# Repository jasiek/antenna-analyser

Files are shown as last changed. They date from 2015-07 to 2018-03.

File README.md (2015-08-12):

# antenna-analyser

There's a few projects like this one out there on the net. My goal was to create one that would be properly productized - eg.
with a PCB ready to be made and a parts list that can be easily obtained on eBay, etc.

The circuit is [K6BEZ's design](https://sites.google.com/site/k6bezprojects/antenna-analyser), and uses
an [Arduino Pro Mini](https://www.arduino.cc/en/Main/ArduinoBoardProMini), running at 8Mhz and 3.3V with
a cheap [SPI LCD TFT display](http://www.electrodragon.com/product/eds-tft-lcd-lcm-spi-interface-variable1-82-2)
to graphically represent the results of VSWR analysis.

I've bundled everything together into one repository so that the project can quickly be opened up in [KiCad](http://www.kicad-pcb.org/)
and the Arduino IDE.

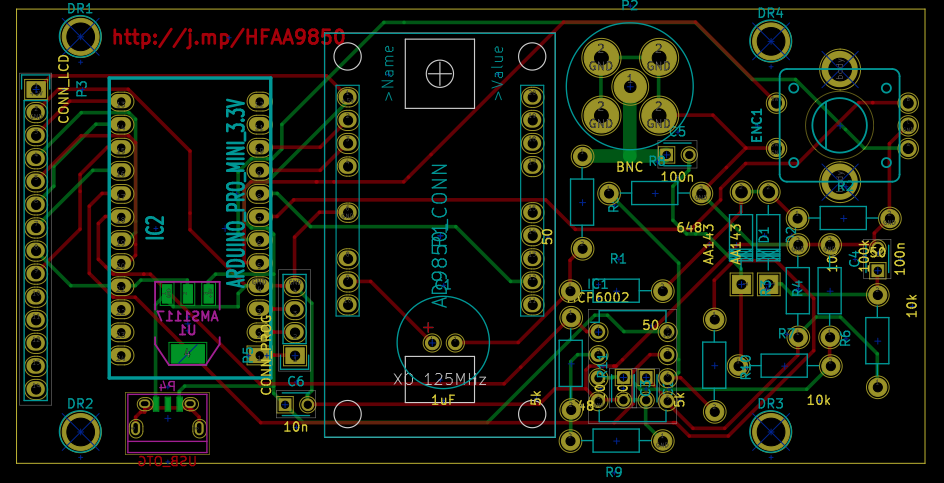
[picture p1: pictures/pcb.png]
PCB

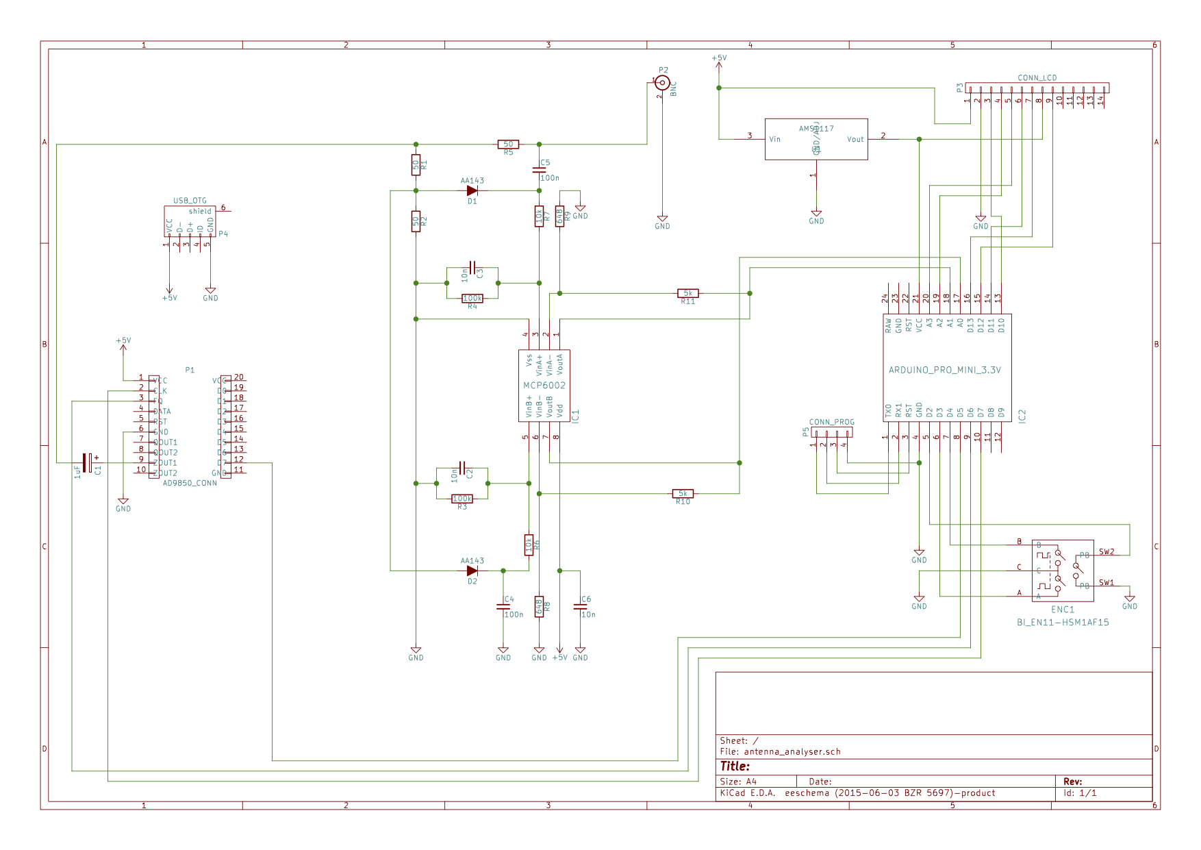
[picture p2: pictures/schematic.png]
Schematic


## A few photos of the first prototype

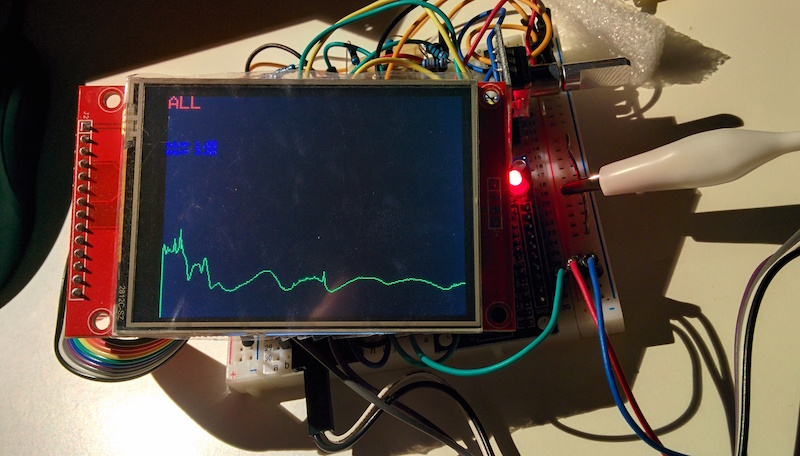
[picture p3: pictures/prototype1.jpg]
Prototype

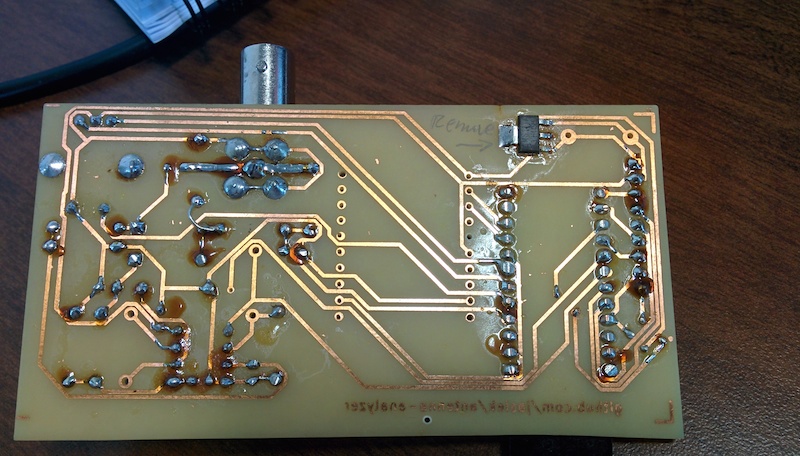
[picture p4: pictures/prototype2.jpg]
Back of PCB

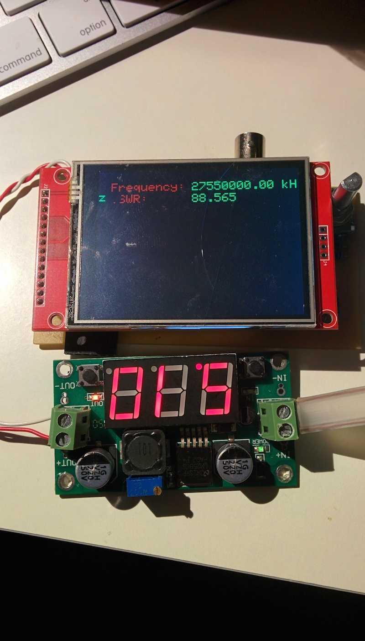
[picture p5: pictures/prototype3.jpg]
Assembled Prototype


## A few shots of the UI

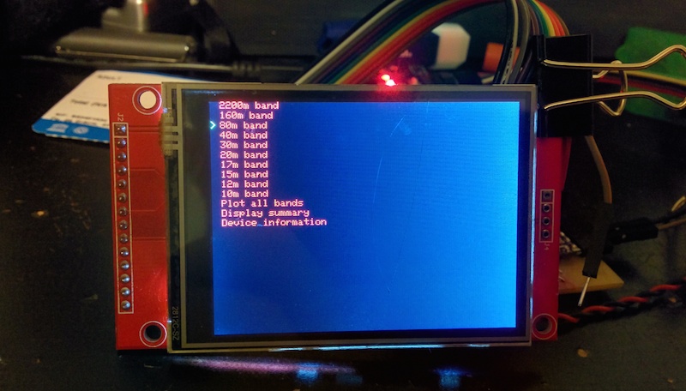
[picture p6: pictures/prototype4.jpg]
Main menu

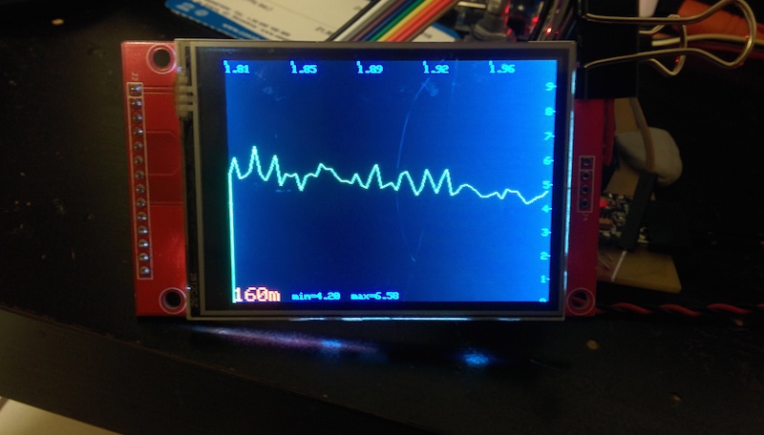
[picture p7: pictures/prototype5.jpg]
Single band plot

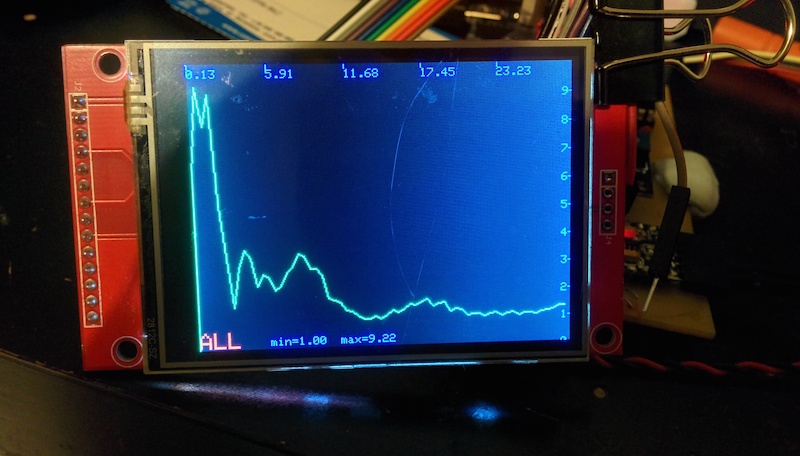
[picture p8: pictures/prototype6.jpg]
All bands plot

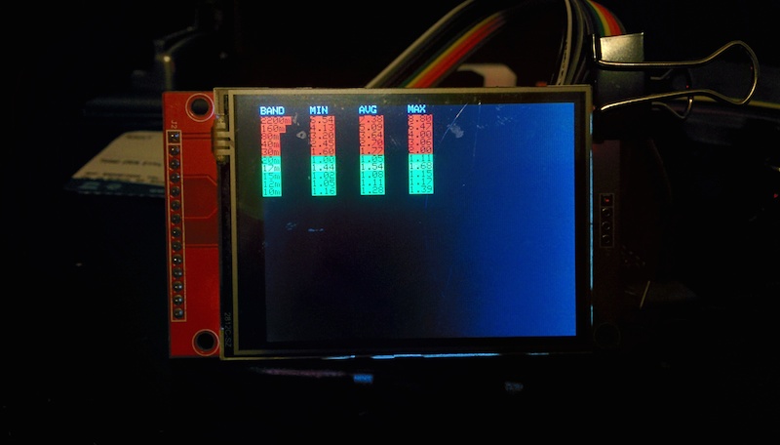
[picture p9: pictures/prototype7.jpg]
Summary table


## TODO

* Build and test this branch as a functional, physical prototype.
* ~~Improve menu structure and navigation.~~
* ~~Improve single band plot (move band label, min, max to the bottom). Notify the user when done plotting.~~
* When plotting all bands, plot amateur bands using a different colour.
* ~~Improve summary view, label columns, shorten frequency label.~~
* Add menu which lists 20 SWR minima across the band.

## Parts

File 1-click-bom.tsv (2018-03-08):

References | Qty | Description | Manufacturer | MPN | Digikey | Mouser | RS | Newark | Farnell
C1 | 1 | 1uF THT | Panasonic | ECA-2GM010
C3, C6, C2 | 3 | 10nF THT | Murata | DSN6NZ81H103Q55B
C5, C4 | 2 | 100nF THT | AVX | TAP104K035SCS
D1, D2 | 2 | AA143 Diode | Microsemi | AA143
ENC1 | 1 | BI EN11-HSM1AF15 | BI Technologies | EN11-HSM1AF15
IC1 | 1 | MCP6002 | Microchip | MCP6002-I/P
IC2 | 1 | Arduino Pro Mini | SparkFun | 11114
P1 | 1 | AD9850 CONN DDS
P2 | 1 | BNC Connector |  | 5-1634556-0
P3 | 1 | CONN 01X14 LCD Connector, single row, 01x14, pin header Socket Strip Straight 1x14 |  | 9-146281-0
P4 | 1 | USB Micro-B | TE Connectivity | 1981568-1
P5 | 1 | CONN 01X04 PROG Connector, single row, 01x04, pin header Socket Strip Straight 1x04 |  | 9-146281-0
R2, R1, R5 | 3 | 50 Ohm THT Resistor |  | PTF5650R000BYEK
R4, R3 | 2 | 100k THT Resistor |  | MF12 100K
R7, R6 | 2 | 10k THT Resistor |  | MF12 10K
R9, R8 | 2 | 648 Ohm THT Resistor |  | RN60C6490FB14
R10, R11 | 2 | 5k THT Resistor |  | RN55C5001BRE6
U1 | 1 | AMS1117-3.3 | Advanced Monolithic Systems | AMS1117-3.3

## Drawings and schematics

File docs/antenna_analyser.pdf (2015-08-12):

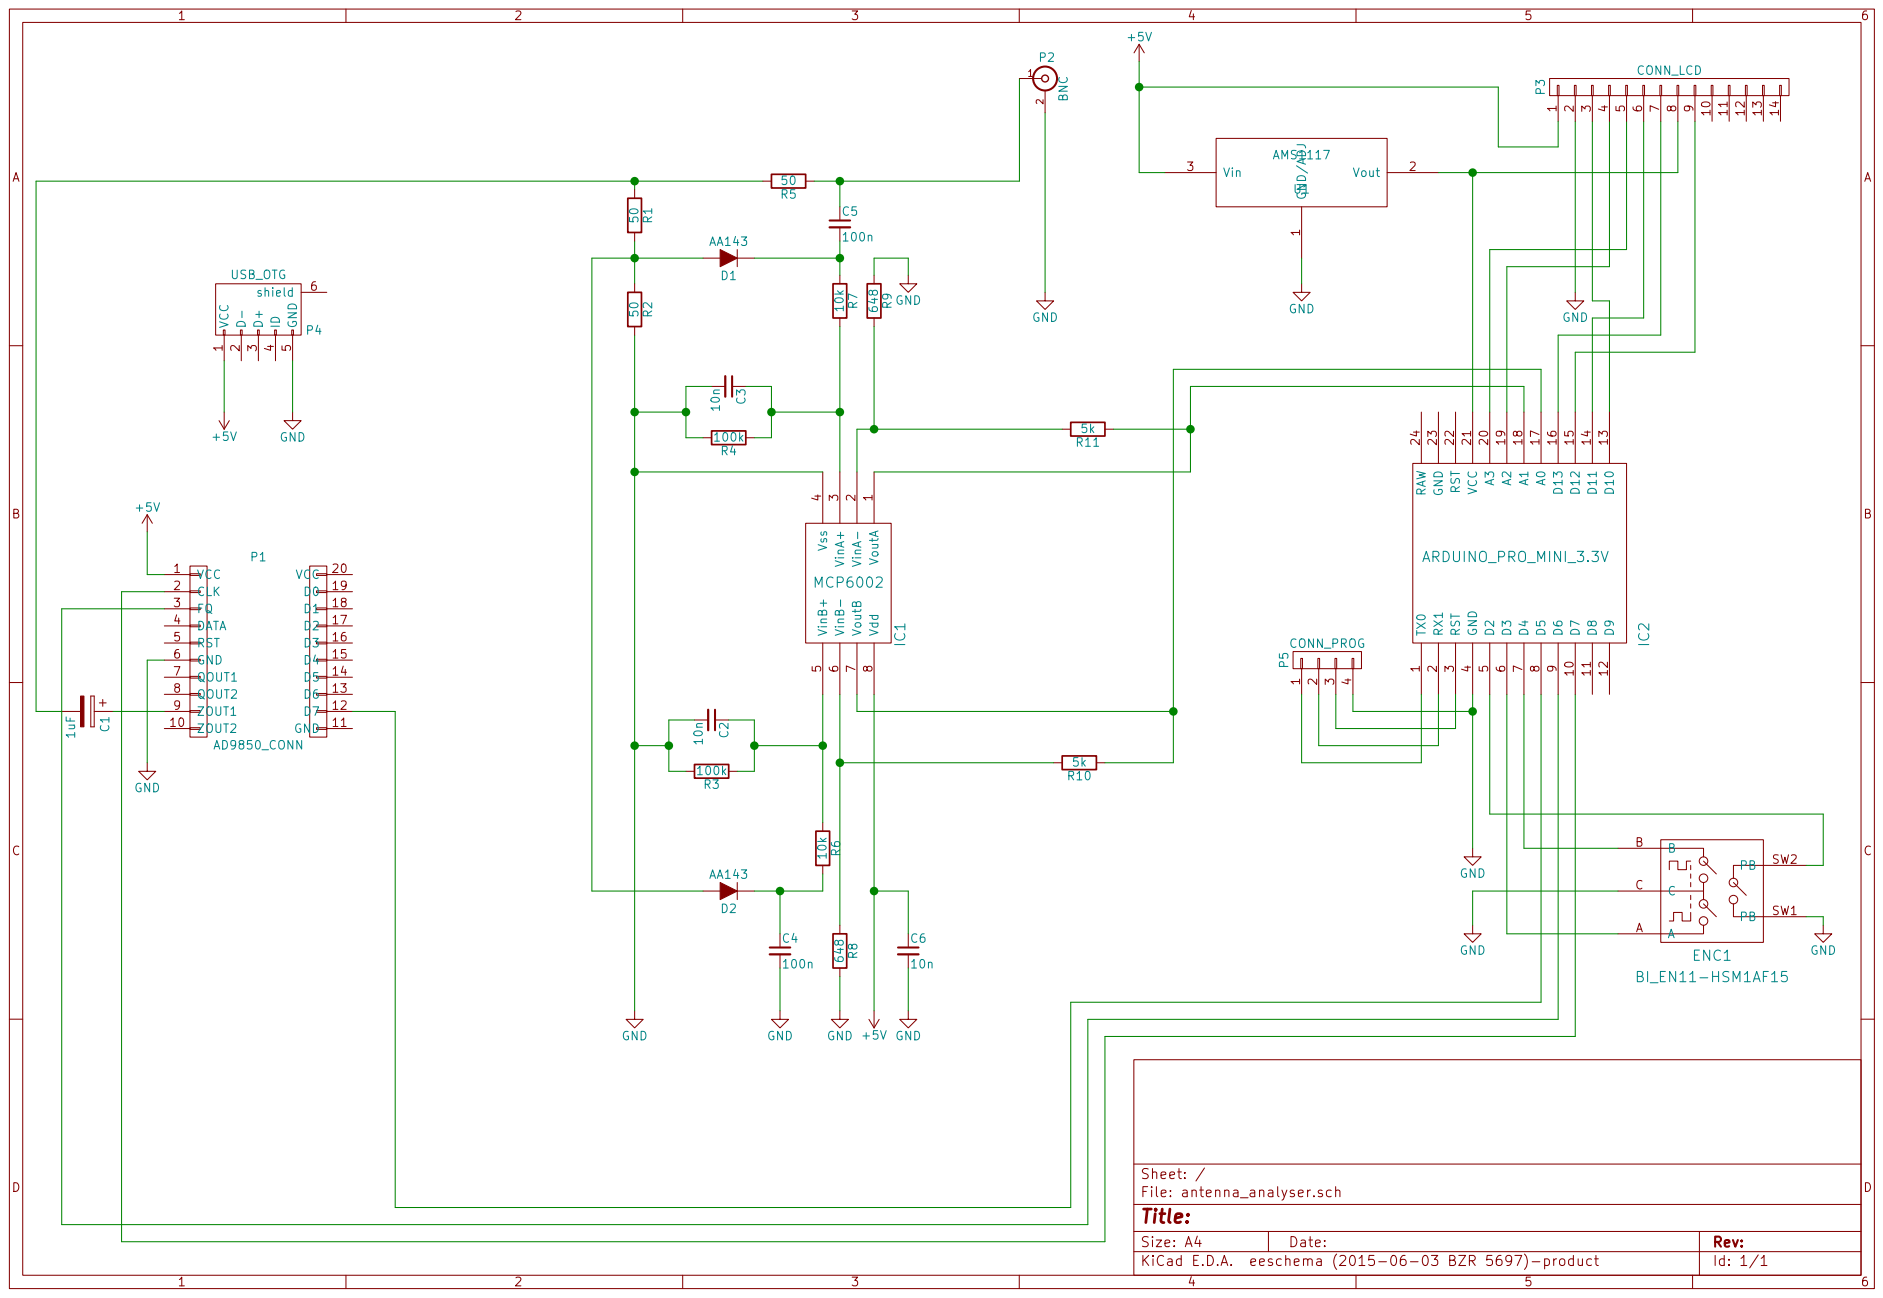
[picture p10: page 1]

2 P2 BNC GND GND VCC

9 D7 10 A3 20 D8 11 VCC 21 D9 12 RST 22 D10 13 GND 23 D11 14 RAW 24 D12 15 D13 16 A0 17 A1 18 A2 19 IC2

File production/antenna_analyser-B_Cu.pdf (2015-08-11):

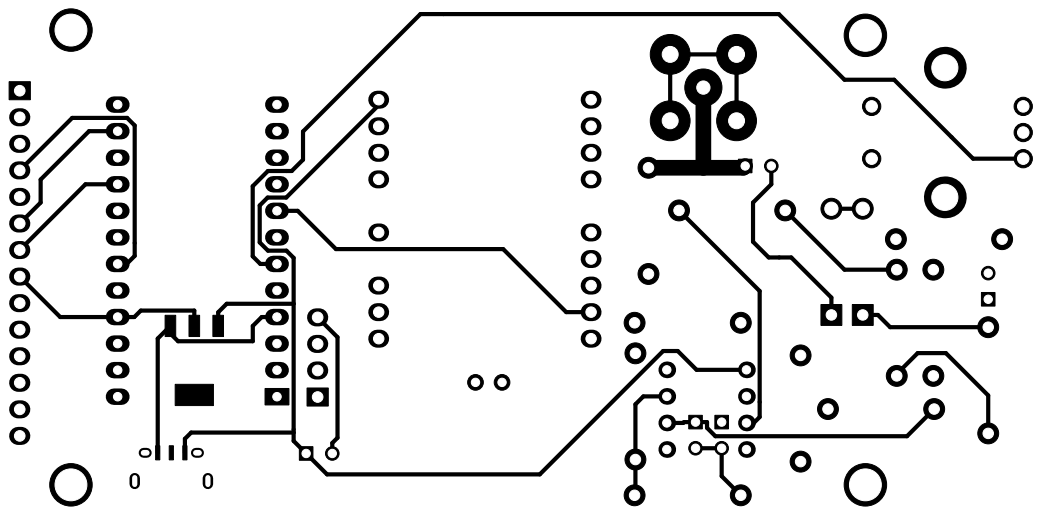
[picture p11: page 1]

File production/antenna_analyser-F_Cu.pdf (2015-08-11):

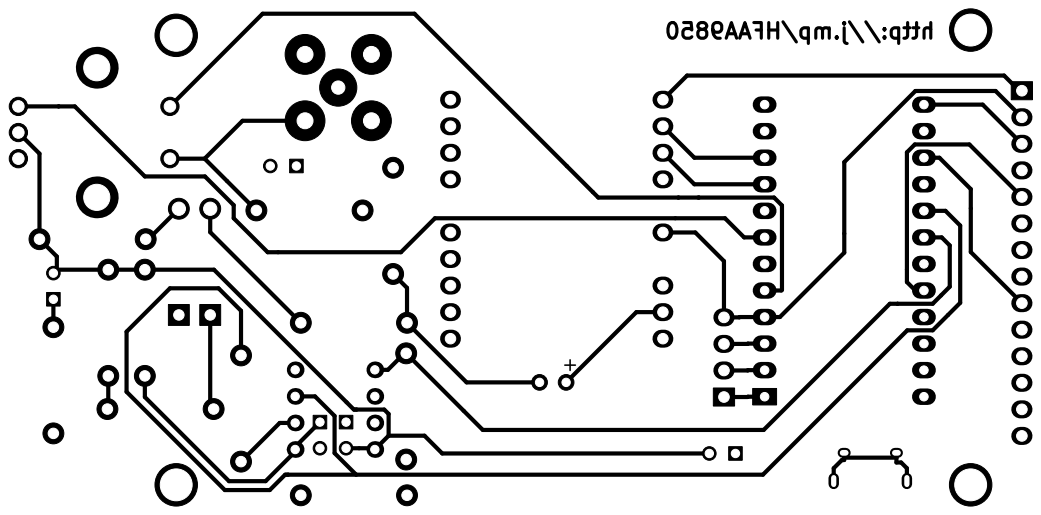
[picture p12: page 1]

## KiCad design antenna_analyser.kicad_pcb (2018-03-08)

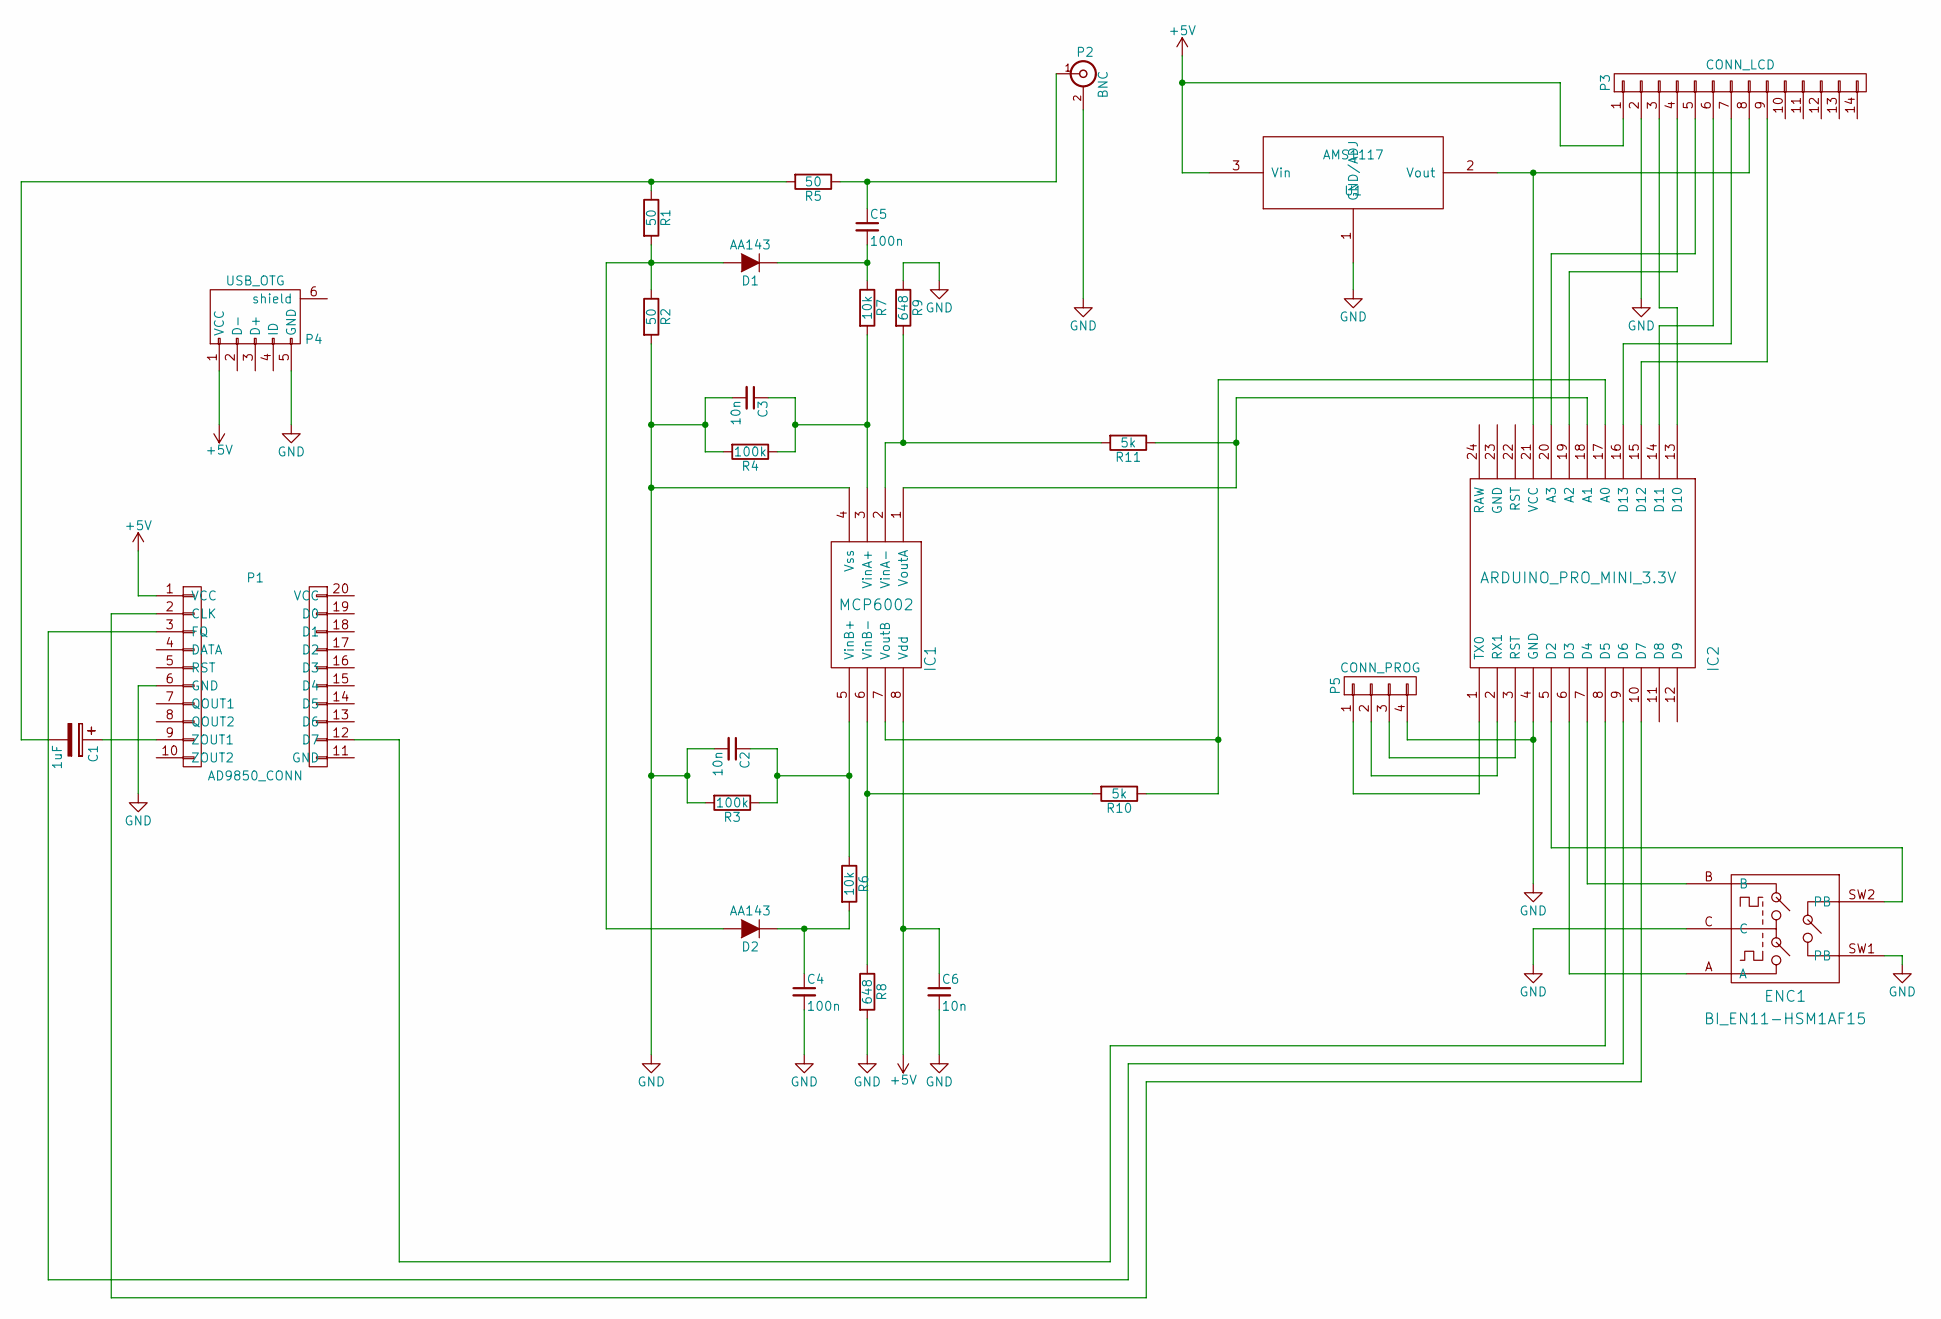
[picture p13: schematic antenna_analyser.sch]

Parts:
C1: 1uF; Elko_vert_20x10mm_RM2.5
C2, C3, C6: 10n; C_Disc_D3_P2.5
C4, C5: 100n; C_Disc_D3_P2.5
D1, D2: AA143; Diode_DO-41_SOD81_Horizontal_RM10
ENC1: BI_EN11-HSM1AF15; BI_EN12-HS22AF30
IC1: MCP6002; DIP-8_W7.62mm
IC2: ARDUINO_PRO_MINI_3.3V; ARDUINO_PRO_MINI
P1: AD9850_CONN; DDS_AD9850
P2: BNC; bnc-ci
P3: CONN_LCD; Socket_Strip_Straight_1x14
P4: USB_OTG; USB_Micro-B
P5: CONN_PROG; Socket_Strip_Straight_1x04
R1, R2, R5: 50; Resistor_Horizontal_RM10mm
R3, R4: 100k; Resistor_Horizontal_RM10mm
R6, R7: 10k; Resistor_Horizontal_RM10mm
R8, R9: 648; Resistor_Horizontal_RM10mm
R10, R11: 5k; Resistor_Horizontal_RM10mm
U1: AMS1117; SOT223

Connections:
+5V: C6.1, IC1.8 (Vdd), P1.1 (VCC), P3.1, P4.1 (VCC), U1.3 (Vin)
GND: C2.2, C3.2, C4.2, C6.2, ENC1.C, ENC1.SW1 (PB), IC1.4 (Vss), IC2.4 (GND), P1.6 (GND), P2.2 (Ext), P3.2, P4.5 (GND), P5.4, R2.2, R3.2, R4.2, R8.2, R9.1, U1.1 (GND/ADJ)
unnamed: C1.1, P1.9 (ZOUT1)
unnamed: C1.2, R1.1, R5.2
unnamed: C2.1, IC1.5 (VinB+), R3.1, R6.1
unnamed: C3.1, IC1.3 (VinA+), R4.1, R7.2
unnamed: C4.1, D2.1 (K), R6.2
unnamed: C5.1, P2.1 (In), R5.1
unnamed: C5.2, D1.1 (K), R7.1
unnamed: D1.2 (A), D2.2 (A), R1.2, R2.1
unnamed: ENC1.A, IC2.6 (D3)
unnamed: ENC1.B, IC2.7 (D4)
unnamed: ENC1.SW2 (PB), IC2.5 (D2)
unnamed: IC1.1 (VoutA), IC2.18 (A1), R11.1
unnamed: IC1.2 (VinA-), R9.2, R11.2
unnamed: IC1.6 (VinB-), R8.1, R10.2
unnamed: IC1.7 (VoutB), IC2.17 (A0), R10.1
unnamed: IC2.1 (TX0), P5.1
unnamed: IC2.2 (RX1), P5.2
unnamed: IC2.3 (RST), P5.3
unnamed: IC2.8 (D5), P1.12 (D7)
unnamed: IC2.9 (D6), P1.3 (FQ)
unnamed: IC2.10 (D7), P1.2 (CLK)
unnamed: IC2.13 (D10), P3.3
unnamed: IC2.14 (D11), P3.6
unnamed: IC2.15 (D12), P3.9
unnamed: IC2.16 (D13), P3.7
unnamed: IC2.19 (A2), P3.4
unnamed: IC2.20 (A3), P3.5
unnamed: IC2.21 (VCC), P3.8, U1.2 (Vout)

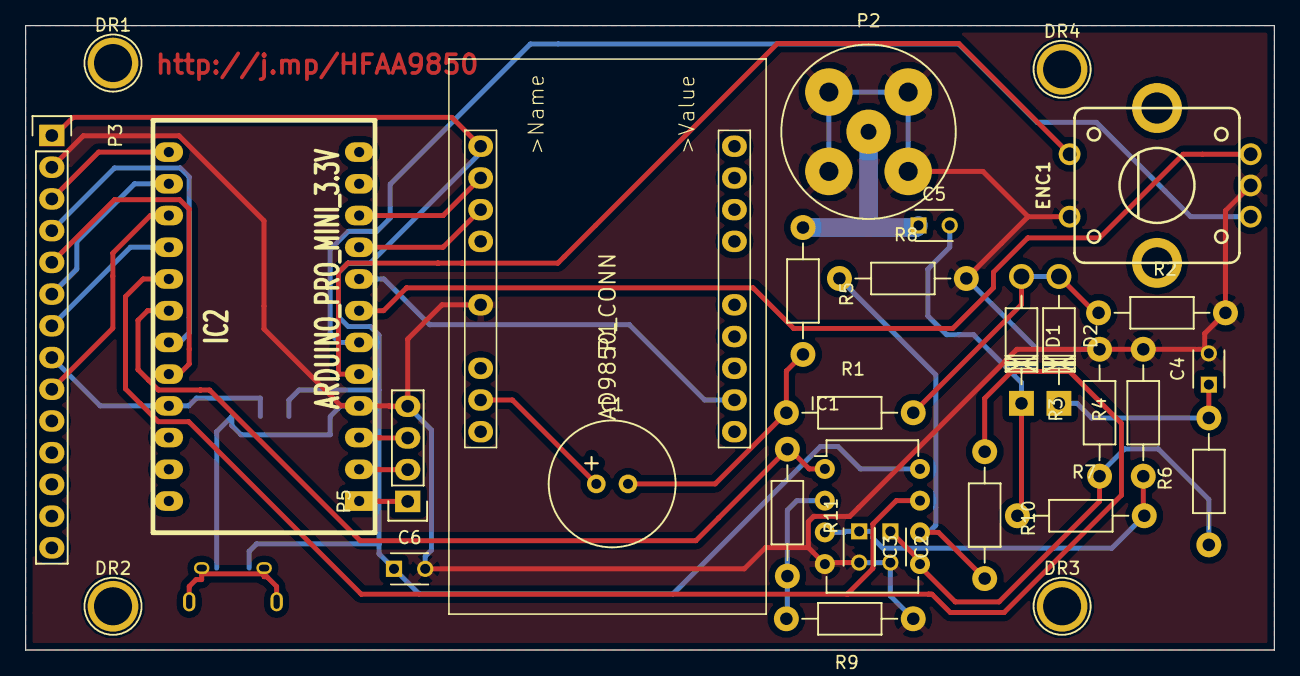
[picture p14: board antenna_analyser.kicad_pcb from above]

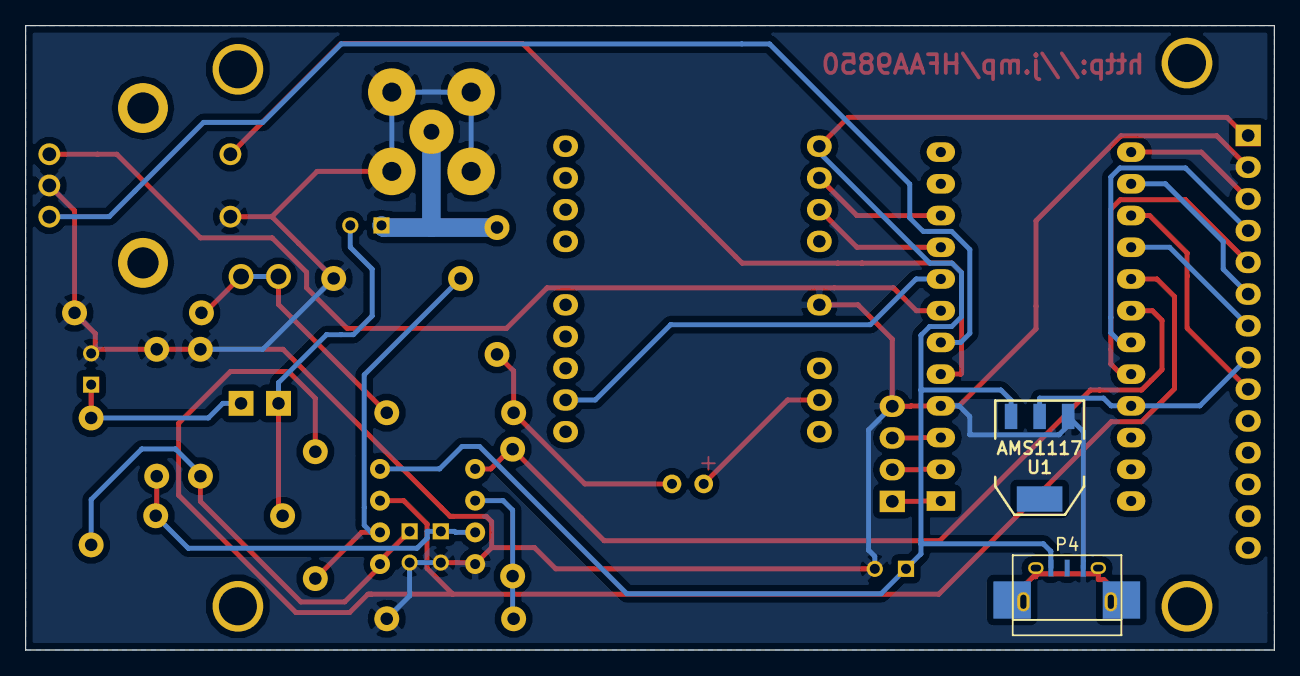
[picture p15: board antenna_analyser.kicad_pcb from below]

Board: 2 copper layers, 100.0 x 50.0 mm, 32 parts (2 on the bottom side), 30 nets.

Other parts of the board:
DR1, DR2, DR3, DR4: 1pin

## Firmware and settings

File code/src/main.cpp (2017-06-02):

#include "SPI.h"
#include "Adafruit_GFX.h"
#include "Adafruit_ILI9341.h"
#include <AD9850.h>

#define BACKGROUND ILI9341_BLACK
#define X_TICS 5
#define Y_TICS 10

#define TABLEN 50
#define T0 0
#define T1 T0 + TABLEN
#define T2 T1 + TABLEN
#define T3 T2 + TABLEN
#define T4 T3 + TABLEN

// Analog pins are used for communication to make the circuit fit on a PCB easier.
Adafruit_ILI9341 tft = Adafruit_ILI9341(10, A3, A2);
AD9850 ad9850;

const String nameOfBand[] =  { "2200m",    "160m",     "80m",    "40m",    "30m",    "20m",    "17m",    "15m",      "12m",    "10m"   };
const double startOfBand[] = { 135.7E3,    1.81E6,     3.5E6,    7E6,      10.1E6,   14E6,     18.068E6,  21E6,      24.89E6,  28E6    };
const double endOfBand[] =   { 137.8E3,    2E6,        3.8E6,    7.2E6,    10.15E6,  14.35E6,  18.168E6,  21.450E6,  24.99E6,  29.7E6  };
const double steps[] =       { 100,        3E3,        3E3,      3E3,      300,      3E3,      3E3,       3E3,       3E3,      6E3     };
const int numBands = 10;

// What kind of actions can be performed using the rotary encoder?
typedef enum {
  NONE,
  CLICK,
  LEFT,
  RIGHT
} Action;

float measureSWR(double f);
void drawXAxis(double begin, double end, byte nticks);
void drawYAxis(byte nticks);
void drawXAxisLabels(String bandLabel);
void sweepBand(double begin, double end, double step, float *min, float *avg, float *max);
void displayPlot(double begin, double end, String label);
void rollHandler();
void clickHandler();
byte awaitAction();
void displaySingleBand(byte band);
void displayAllBands();
void displaySummary();
void displayInfo();
byte mainMenu();

void setup() {
  pinMode(2, INPUT_PULLUP); // Rotary encoder CLK
  pinMode(3, INPUT_PULLUP); // Rotary encoder CLICK
  pinMode(4, INPUT_PULLUP); // Rotary encoder DATA

  Serial.begin(57600);
  tft.begin();
  Serial.println("Width: " + String(tft.width()) + " Height: " + String(tft.height()));
  tft.setRotation(3);
  ad9850.begin(7, 6, 5, 0);
}

void loop() {
  byte nextUIState = 100;

  while(1) {
    tft.fillScreen(BACKGROUND);

    switch(nextUIState) {
      case 100:
        nextUIState = mainMenu();
        break;
      case numBands:
        displayAllBands();
        nextUIState = 100;
        break;
      case numBands + 1:
        displaySummary();
        nextUIState = 100;
        break;
      case numBands + 2:
        displayInfo();
        nextUIState = 100;
        break;
      default:
        displaySingleBand(nextUIState);
        nextUIState = 100;
        break;
    }
  }
}

// Display the main menu and handle view changes resulting from the operation of the
// rotary encoder.
// Returns to calling function when this menu is dismissed, communicating the menu state up the chain.
byte mainMenu() {
  const byte menuEntries = numBands + 3;
  byte menuState = 0;
  byte i;
  tft.setTextSize(1);
  tft.setTextColor(ILI9341_RED, BACKGROUND);
  for (i = 0; i < numBands; i++) {
    tft.setCursor(10, i * 10);
    tft.print(nameOfBand[i] + " band");
  }

  tft.setCursor(10, 10 * (numBands));
  tft.print("Plot all bands");
  tft.setCursor(10, 10 * (numBands + 1));
  tft.print("Display summary");
  tft.setCursor(10, 10 * (numBands + 2));
  tft.print("Device information");

  while (1) {
    for (i = 0; i < menuEntries; i++) {
      tft.setCursor(0, i * 10);
      if (menuState == i) { tft.setTextColor(ILI9341_YELLOW, BACKGROUND); } else { tft.setTextColor(BACKGROUND, BACKGROUND); }
      tft.print(">");
    }

    switch(awaitAction()) {
      case CLICK:
        return menuState;
      case LEFT:
        menuState = (menuState - 1) % menuEntries;
        break;
      case RIGHT:
        menuState = (menuState + 1) % menuEntries;
        break;
    }
  }
}

// Await user interaction by setting interrupt handlers and looping on a variable modified from
// within an ISR.
volatile Action selectedAction;
byte awaitAction() {
  selectedAction = NONE;

  detachInterrupt(0);
  detachInterrupt(1);
  attachInterrupt(0, clickHandler, CHANGE);
  attachInterrupt(1, rollHandler, FALLING);
  interrupts();

  while (selectedAction == NONE);
  return selectedAction;
}

// Handles left- and right-turns on the rotary encoder
void rollHandler() {
  noInterrupts();

  selectedAction = (digitalRead(2) == digitalRead(4)) ? LEFT : RIGHT;
}

// Handles clicks on the rotary encoder
void clickHandler() {
  noInterrupts();

  selectedAction = CLICK;
}

void displayInfo() {
  tft.fillScreen(BACKGROUND);
  tft.setTextSize(2);
  tft.setCursor(0, 0);
  tft.setTextColor(ILI9341_RED, BACKGROUND);
  tft.println("HF Antenna Analyzer");
  tft.println();

  tft.setTextColor(ILI9341_YELLOW, BACKGROUND);
  tft.setTextSize(1);
  tft.println("Based on hardware design by Beric Dunn (K6BEZ)");
  tft.println("Software by Jan Szumiec (M0NIT)");
  tft.println();
  tft.println("Build: " + String(__DATE__) + " " + String(__TIME__));

  awaitAction();
}

// Display a plot for all bands, when done - press button or rotate to exit
void displayAllBands() {
  displayPlot(135E3, 29E6, "ALL");
  awaitAction();
}

// Display a plot for a single band, when done - press button or rotate to exit
void displaySingleBand(byte band) {
  displayPlot(startOfBand[band], endOfBand[band], nameOfBand[band]);
  awaitAction();
}

// Display a textual summary for all bands
// band name, minimum SWR, maximum SWR
// background color indicates suitability (red-amber-green)
void displaySummary() {
  tft.setCursor(T0, 0);
  tft.setTextSize(1);
  tft.setTextColor(ILI9341_WHITE, BACKGROUND);
  tft.print("BAND");
  tft.setCursor(T1, 0);
  tft.print("MIN");
  tft.setCursor(T2, 0);
  tft.print("AVG");
  tft.setCursor(T3, 0);
  tft.print("MAX");

  float min, avg, max;
  int bgcolor;

  for (int i = 0; i < numBands; i++) {
    sweepBand(startOfBand[i], endOfBand[i], steps[i], &min, &avg, &max);
    byte row = 10 + i * 8;

    bgcolor = ILI9341_RED;
    if (avg < 1.6) { bgcolor = ILI9341_YELLOW; }
    if (avg < 1.3) { bgcolor = ILI9341_GREEN; }
    tft.setTextColor(ILI9341_BLACK, bgcolor);

    tft.setCursor(T0, row);
    tft.print(nameOfBand[i]);
    tft.setCursor(T1, row);
    tft.print(min);
    tft.setCursor(T2, row);
    tft.print(avg);
    tft.setCursor(T3, row);
    tft.print(max);
  }

  awaitAction();
}

void sweepBand(double begin, double end, double step, float *min, float *avg, float *max) {
  *min = 99999;
  *max = 0;
  float sum = 0;
  float swr;
  int count = 0;
  double f;

  for (f = begin; f < end; f += step) {
    swr = measureSWR(f);
    if (swr > *max) { *max = swr; }
    if (swr < *min) { *min = swr; }
    sum += swr;
    count ++;
  }
  *avg = sum / count;
}

void displayPlot(double begin, double end, String label) {
  tft.fillScreen(BACKGROUND);

  double xstep = (end - begin) / tft.width();
  double ystep = tft.height() / Y_TICS;

  drawXAxis(begin, end, X_TICS);
  drawYAxis(Y_TICS);
  drawXAxisLabels(label);

  float maxSWR = 0;
  float minSWR = 1000;

  Serial.println("start= " + String(begin));
  Serial.println("end  = " + String(end));
  Serial.println("xstep= " + String(xstep));
  Serial.println("ystep= " + String(ystep));

  int prevx = 0;
  int prevy = 240;
  for (int x = 0; x < tft.width(); x += 5) {
    double f = begin + x * xstep;
    float swr = measureSWR(f);

    if (swr < minSWR) { minSWR = swr; }
    if (swr > maxSWR) { maxSWR = swr; }

    int y = tft.height() - swr * ystep;
    tft.drawLine(prevx, prevy, x, y, ILI9341_GREEN);
    prevx = x;
    prevy = y;
  }

  tft.setTextSize(1);
  tft.setTextColor(ILI9341_BLUE, BACKGROUND);
  tft.setCursor(60, tft.height() - 10);
  tft.print("min=" + String(minSWR));
  tft.setCursor(120, tft.height() - 10);
  tft.print("max=" + String(maxSWR));
}

void drawXAxisLabels(String bandLabel) {
  tft.setTextSize(2);
  tft.setCursor(0, tft.height() - 15);
  tft.setTextColor(ILI9341_RED);
  tft.print(bandLabel);
}

void drawXAxis(double begin, double end, byte nticks) {
  tft.setTextSize(1);
  tft.setTextColor(ILI9341_BLUE, BACKGROUND);
  byte n, xstep = tft.width() / nticks;
  double fstep = (end - begin) / nticks;

  for (n = 0; n < nticks; n++) {
    tft.drawLine(n * xstep, 0, n * xstep, 3, ILI9341_BLUE);
    tft.setCursor(n * xstep, 4);
    tft.print((begin + n * fstep) / 1E6);
  }
}

void drawYAxis(byte nticks) {
  tft.setTextSize(1);
  tft.setTextColor(ILI9341_BLUE, BACKGROUND);
  byte n, ystep = tft.height() / nticks;
  for (n = nticks; n > 0; n--) {
    tft.drawLine(tft.width() - 1, n * ystep, tft.width() - 3, n * ystep, ILI9341_BLUE);
    tft.setCursor(tft.width() - 8, n * ystep - 3);
    tft.print(nticks - n);
  }
}

float measureSWR(double f) {
  float fwd, rev;
  ad9850.setfreq(f, 0);
  delay(10);
  fwd = analogRead(A0);
  rev = analogRead(A1);

  if (rev >= fwd) {
    return 999;
  } else {
    return (fwd + rev) / (fwd - rev);
  }
}

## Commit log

2015-06-05 Updated element references and their values.
    [antenna_analyser.sch]
2015-06-24 Minor updates.
    [antenna_analyser.kicad_pcb, antenna_analyser.sch]
2015-06-24 Updated library references.
    [antenna_analyser.sch]
2015-06-24 Added Edge SMA connectors library from:
    http://www.kicadlib.org/modules/JOS_SMA_connectors.zip
2015-06-24 The antenna connector is an SMA edge connector now.
    [antenna_analyser.sch]
2015-06-24 Squashed 'libs/jasiek/' content from commit c7b7a3a
    git-subtree-dir: libs/jasiek
    git-subtree-split: c7b7a3a78ed0fb45c8dd56f6ba5fb27df050de2e
    [sop8breakout.kicad_pcb, sop8breakout.sch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]
2015-06-24 The MCP6002 part now references footprints I designed for a breakout board.
2015-06-24 Added a footprint library for the AD9850 from here:
    http://nyfiken.org/arkiv/402
2015-06-26 Added Arduino Pro Mini footprints from:
    http://www.kicadcloud.com/pcbModule/4420
2015-06-26 Added an Arduino and a voltage regulator to the schematics.
    [antenna_analyser.sch]
2015-06-28 Added a footprint library entry for the AD9850 module.
2015-06-28 Updates to the schematic.
    Replaced 50ohm and 5kohm resistors with their equivalent parallel circuits.
    Added an AD9850 module to the schematic for easier reference.
    [antenna_analyser.kicad_pcb, antenna_analyser.sch]
2015-07-02 Use hardware SPI instead (duh!).
2015-07-04 Added a connector for the LCD display.
    [antenna_analyser.sch]
2015-07-04 Added a rotary encoder library (might not be the right!) from:
    http://www.kicadlib.org/modules/KM_rotary-switch.zip
2015-07-04 Added a switch for changing modes of operation, and a rotary encoder to change the frequency.
    [antenna_analyser.sch]
2015-07-05 Updated code to display a plot of SWR versus frequency, and tested on my local antenna.
2015-07-06 Removed KM library.
    [antenna_analyser.sch]
2015-07-06 Added an edge connector for the rotary encoder.
    [antenna_analyser.sch]
2015-07-07 PCB first attempt, no luck. Need to make sure the elements are on the correct side.
    [antenna_analyser.kicad_pcb, antenna_analyser.sch]
2015-07-07 MCP6002 is now properly attached on the PCB. The arduino board is attached as well. PCB needs work to be one-sided only.
    [antenna_analyser.kicad_pcb, antenna_analyser.sch]
2015-07-07 Playing with freerouting, need to lay components according to a semi-planar schema and run freerouting on it.
    [antenna_analyser.kicad_pcb, antenna_analyser.sch]
2015-07-08 Added a photo of my prototype.
2015-07-08 Moving some components around so that freerouting can produce a single sided PCB.
    [antenna_analyser.kicad_pcb]
2015-07-12 Use analog pins to have all LCD connectors on one side.
2015-07-12 50/5k ohm resistors
    [antenna_analyser.kicad_pcb, antenna_analyser.sch]
2015-07-14 Track laying, cont'd.
    [antenna_analyser.kicad_pcb]
2015-07-15 Final PCB
    [antenna_analyser.dsn, antenna_analyser.kicad_pcb]
2015-08-04 There are three options in the main menu, each is selectable using a rotary encoder + a click. Refresh rate is decent.
2015-08-08 Added a USB micro connector, and a 14-pin strip socket for the LCD.
    [antenna_analyser.sch]
2015-08-08 Added programming connector.
    [antenna_analyser.sch]
2015-08-08 Preliminary part layout
    [antenna_analyser.dsn, antenna_analyser.kicad_pcb]
2015-08-09 Two-sided PCB with a USB connector and programming pins.
    [antenna_analyser.dsn, antenna_analyser.kicad_pcb]
2015-08-09 Another 2-sided PCB interation, this time with mounting points.
    [antenna_analyser.dsn, antenna_analyser.kicad_pcb]
2015-08-11 Straightened and simplified a couple of tracks.
    [antenna_analyser.kicad_pcb]
2015-08-11 Embiggened pads on the AD9850, removed some pads to make way for tracks.
    [antenna_analyser.kicad_pcb]
2015-08-11 Added a shortlink to the github site:
    http://j.mp/HFAA9850
    [antenna_analyser.kicad_pcb]
2015-08-11 A few mods more.
    [antenna_analyser.kicad_pcb]
2015-08-11 Production-ready PDFs (meant to be printed on the same page)
2015-08-11 Final touches.
    [antenna_analyser.kicad_pcb]
2015-08-12 Added schematics and PCB shot.
2015-08-18 Added auxiliary soldering points to make it easier to attach the USB socket to the board.
    [antenna_analyser.kicad_pcb]
2017-05-09 Production artifacts.
    [antenna_analyser-B.Adhes.gbr, antenna_analyser-B.CrtYd.gbr, antenna_analyser-B.Cu.gbr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]
2018-03-08 Added metadata for kitspace.org
    [1-click-bom.tsv]
2018-03-08 Reopened the project with 4.0.7 and regenerated drill files.
    [antenna_analyser-B.Adhes.gbr, antenna_analyser-B.CrtYd.gbr, antenna_analyser-B.Cu.gbr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]
2018-03-08 Updated BOM.
    [1-click-bom.tsv]
